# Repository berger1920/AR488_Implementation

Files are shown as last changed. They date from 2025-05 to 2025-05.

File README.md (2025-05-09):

# AR488_Implementation

This is my implementation of the **AR488 Arduino GPIB Interface** project by **Twilight-Logic**:

[AR488 by Twilight-Logic](https://github.com/Twilight-Logic/AR488)

My immediate need was to be able to take screenshots of my **Tektronix 2232 oscilloscope**: [Tek2232](https://w140.com/tekwiki/wiki/2232)

It has Option10 installed on it (GPIB port but no RS-232).

Since I had several unused Arduino Leonardo boards, I decided to design a PCB shield for UNO/Leonardo, and use a simple and cheap IEE488 cable since the distance between the interface and my oscilloscope is small. So I had no need to use an expensive IEE488 cable.

Cable used: https://aliexpress.com/item/1005002004248810.html

GPIB_Cable

PCB Shield for Arduino and Leonardo designed with KiCad 9.0. Files available in Gerber folder.

PCB-Top_Simul-3D

PCB-Bot_Simul-3D

This is the PCB manufactured at JLCPCB:

PCB

I have designed a simple case with OpenSCAD. The opening between the DC connector and the micro-USB is to allow the LEDs of the Leonardo board to be seen. In case of using Arduino UNO, that opening is unnecessary. My case desing is poor, so in the 3D-print folder you can find not only the .3mf files for direct printing, but also the .scad file for modification and improvement.

3D_Printing

Assembling the interface:

PCB_assembled_01

PCB_assembled_02

PCB_assembled_03

Connecting the AR488 intereface to the Tektronix Oscilloscope and the Laptop:

Installation_01

Installation_02

Installation_03

Installation_04

And a simple printing test:

IRQ

At the moment I only use the interface to take screenshots, using the plotter print option that this oscilloscope has. The oscilloscope sends data in HPGL format, which I capture on a Serial Terminal, and then convert into a vector file (svg) or I can also export as a jpg, png, etc.

As I work only on GNU/Linux, the program I use for the conversion of HPGL into other formats is:

https://www.gnu.org/software/hp2xx/

If you want to ask questions or give feedback, please click here:

https://github.com/Twilight-Logic/AR488/discussions/57

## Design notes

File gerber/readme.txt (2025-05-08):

When using JLCPCB gerber file, remember to select "Order Number (Specify Position)" in "Mark on PCB" option.

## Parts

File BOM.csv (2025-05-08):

Reference | Value | Footprint | Datasheet | Qty | DNP
C1,C2 | 0.1 | Capacitor_THT:C_Axial_L3.8mm_D2.6mm_P7.50mm_Horizontal | ~ | 2
J1 | Power | Connector_PinSocket_2.54mm:PinSocket_1x08_P2.54mm_Vertical | ~ | 1
J2,J4 | Digital/PWM | Connector_PinSocket_2.54mm:PinSocket_1x08_P2.54mm_Vertical,Connector_PinSocket_2.54mm:PinSocket_1x10_P2.54mm_Vertical | ~ | 2
J3 | Analog | Connector_PinSocket_2.54mm:PinSocket_1x06_P2.54mm_Vertical | ~ | 1
J5 | DATA | Connector_PinHeader_2.54mm:PinHeader_1x08_P2.54mm_Vertical | ~ | 1
J6 | CTRL | Connector_PinHeader_2.54mm:PinHeader_1x08_P2.54mm_Vertical | ~ | 1
SW1 | RESET | Button_Switch_THT:SW_PUSH_6mm | ~ | 1
U1 | SN75160BN | Package_DIP:DIP-20_W7.62mm | http://www.ti.com/lit/ds/symlink/sn75160b.pdf | 1
U2 | SN75161BN | Package_DIP:DIP-20_W7.62mm | http://www.ti.com/lit/ds/symlink/sn75161b.pdf | 1

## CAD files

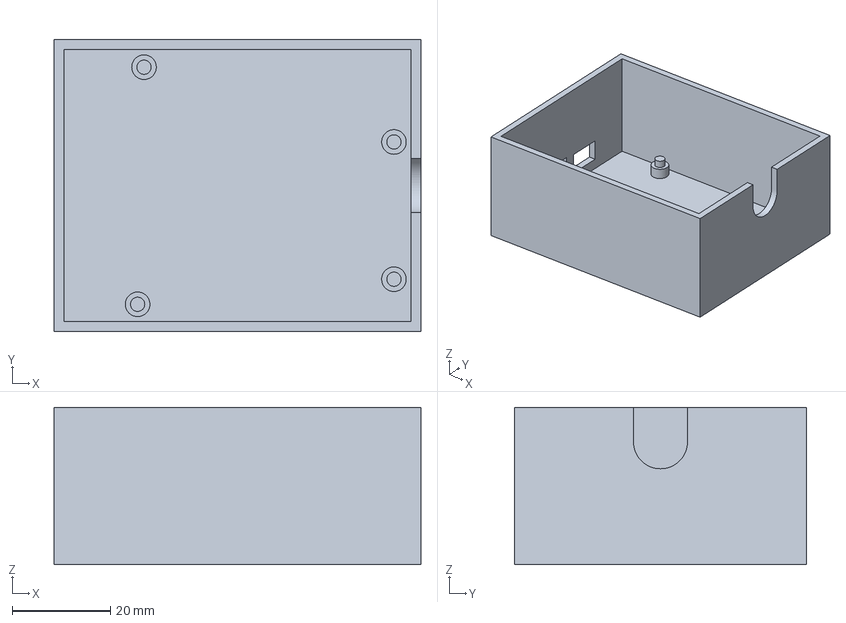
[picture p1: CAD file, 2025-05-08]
3D-print/AR488_case.3mf
74.6 x 59.3 x 32.0 mm

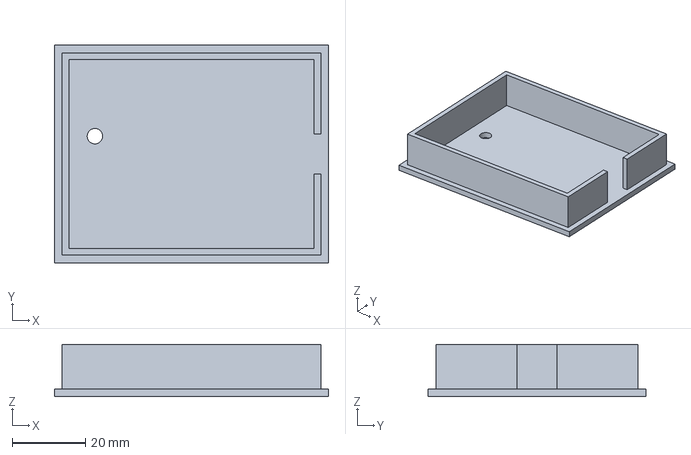
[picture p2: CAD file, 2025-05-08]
3D-print/AR488_cover.3mf
74.6 x 59.3 x 14.2 mm

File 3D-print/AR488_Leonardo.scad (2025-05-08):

// Case for AR488 with Arduino Leonardo
// rev.1 by Gerardo M. (aka Berger)

$fn=64;

xx=68.6;  // PCBs length
yy=53.3;  // PCBs width
zz=27.0;  // PCBs height
wall=2.0;
gap=1.0;  // Around the PCB.
gap2=0.1; // Cover. Depends on the printing.


// Case
difference() {
  
  union() {  
    difference() {
      cube([xx+gap*2+wall*2, yy+gap*2+wall*2, zz+wall+3.0]);
      translate([wall, wall, wall])
        cube([xx+gap*2, yy+gap*2, zz+3.0]);
    }
    
    // Fixings
    translate([wall+gap+14.0, wall+gap+2.5, 0]) {
      cylinder(h=wall+3.0, d=5, center=false);
      cylinder(h=wall+5.0, d=2.9, center=false);
    }
    translate([wall+gap+15.3, wall+gap+50.7, 0]) {
      cylinder(h=wall+3.0, d=5, center=false);
      cylinder(h=wall+5.0, d=2.9, center=false);
    }
    translate([wall+gap+66.1, wall+gap+7.6, 0]) {
      cylinder(h=wall+3.0, d=5, center=false);
      cylinder(h=wall+5.0, d=2.9, center=false);
    }
    translate([wall+gap+66.1, wall+gap+35.5, 0]) {
      cylinder(h=wall+3.0, d=5, center=false);
      cylinder(h=wall+5.0, d=2.9, center=false);
    }
  }
  
  // DC opening
  translate([0, wall+gap+3.5, wall+3.0+1.5])
    cube([wall, 9.5, 11.5]);
  
  // USB opening
  translate([0, wall+gap+33, wall+3.0])
    cube([wall, 10, 6.0]);
  
  // LEDs opening
  translate([0, wall+gap+14, wall+3.0+1.5])
    cube([wall, 15, 5.0]);
  
  // Cable
  translate([xx+gap*2+wall, (yy+gap*2+wall*2)/2, wall+3.0+1.5+13+11/2])
    rotate([0, 90, 0])
    cylinder(h=wall, d=11, center=false);
  translate([xx+gap*2+wall, (yy+gap*2+wall*2)/2-11/2, wall+3.0+1.5+13+11/2])
    cube([wall, 11, 10]);
  
}

/*
// Cover
difference() {
  union() {
  cube([xx+gap*2+wall*2, yy+gap*2+wall*2, wall]);
    translate([wall+gap2, wall+gap2, wall])
      cube([xx+gap*2-gap2*2, yy+gap*2-gap2*2, 12.2]);
  }
  translate([wall+gap2+1.8, wall+gap2+1.8, wall])
    cube([xx+gap*2-gap2*2-1.8*2, yy+gap*2-gap2*2-1.8*2, 12.2]);
  translate([xx+gap*2, (yy+gap*2+wall*2)/2-11/2, wall])
    cube([wall, 11, 12.2]);
  translate([11, 34.5, 0])
    cylinder(h=wall, d=4.2, center=false);
}
*/

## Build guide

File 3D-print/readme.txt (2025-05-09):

OpenSCAD (.scad) file with the two parts of the case
3D Manufacturing Format (.3mf) files

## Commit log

2025-05-08 Create gerber
    Gerber files
2025-05-08 Gerber files
2025-05-08 3D printing
2025-05-08 3D printing files
    [AR488_Leonardo.scad, AR488_case.3mf, AR488_cover.3mf]
2025-05-08 Bill of Materials
    [BOM.csv]
